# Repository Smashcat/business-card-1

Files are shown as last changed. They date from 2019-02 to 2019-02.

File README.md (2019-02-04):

# business-card-1
LED business card with a 15 x 5 LED matrix. Using ATMega168PB microcontroller, and real time clock chip. Powered by single CR2032 coin cell. All SMD parts, so if you're having PCBs made with this design I'd strongly suggest also buying a stencil to make it a LOT easier to solder! In my code I'm using deep sleep, with the button triggering a pin change interrupt to wake it. I use a 10khz timer interrupt to multiplexthe LEDs, which gives a good brightness, and allows for at least 16 greyscale levels.

Note that I'm using 100ohm resistors for the rows - this allows you to run the card at both 3v and 5v - however if you're only using 3v, I'd suggest lowering the resistor value to 50ohms, to increase brightness. 3D printing an acrylic cover to diffuse the LEDs would be a nice touch too! If I get a design done I'll add it here!

Image of card

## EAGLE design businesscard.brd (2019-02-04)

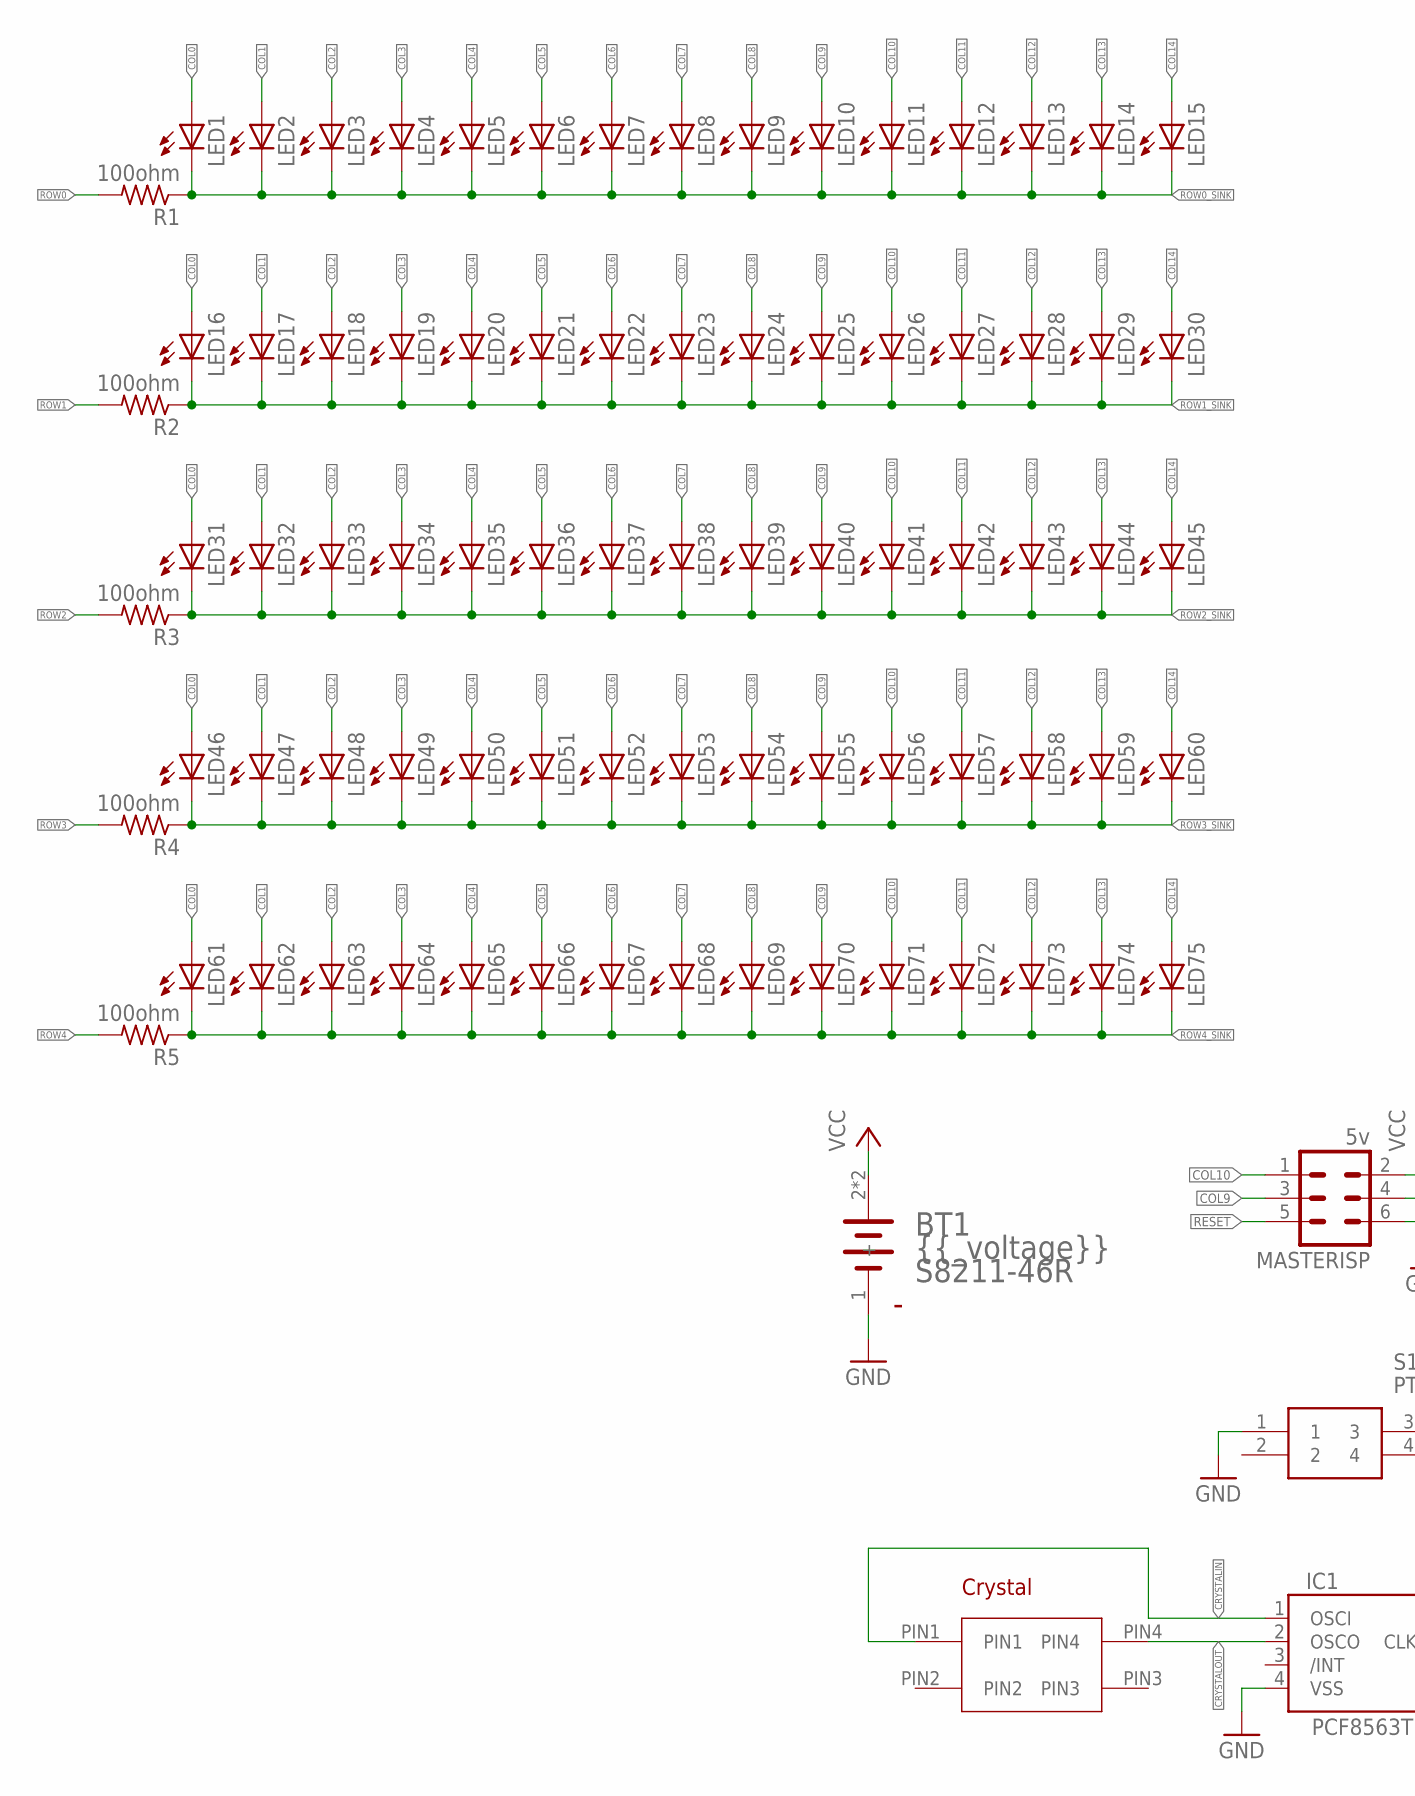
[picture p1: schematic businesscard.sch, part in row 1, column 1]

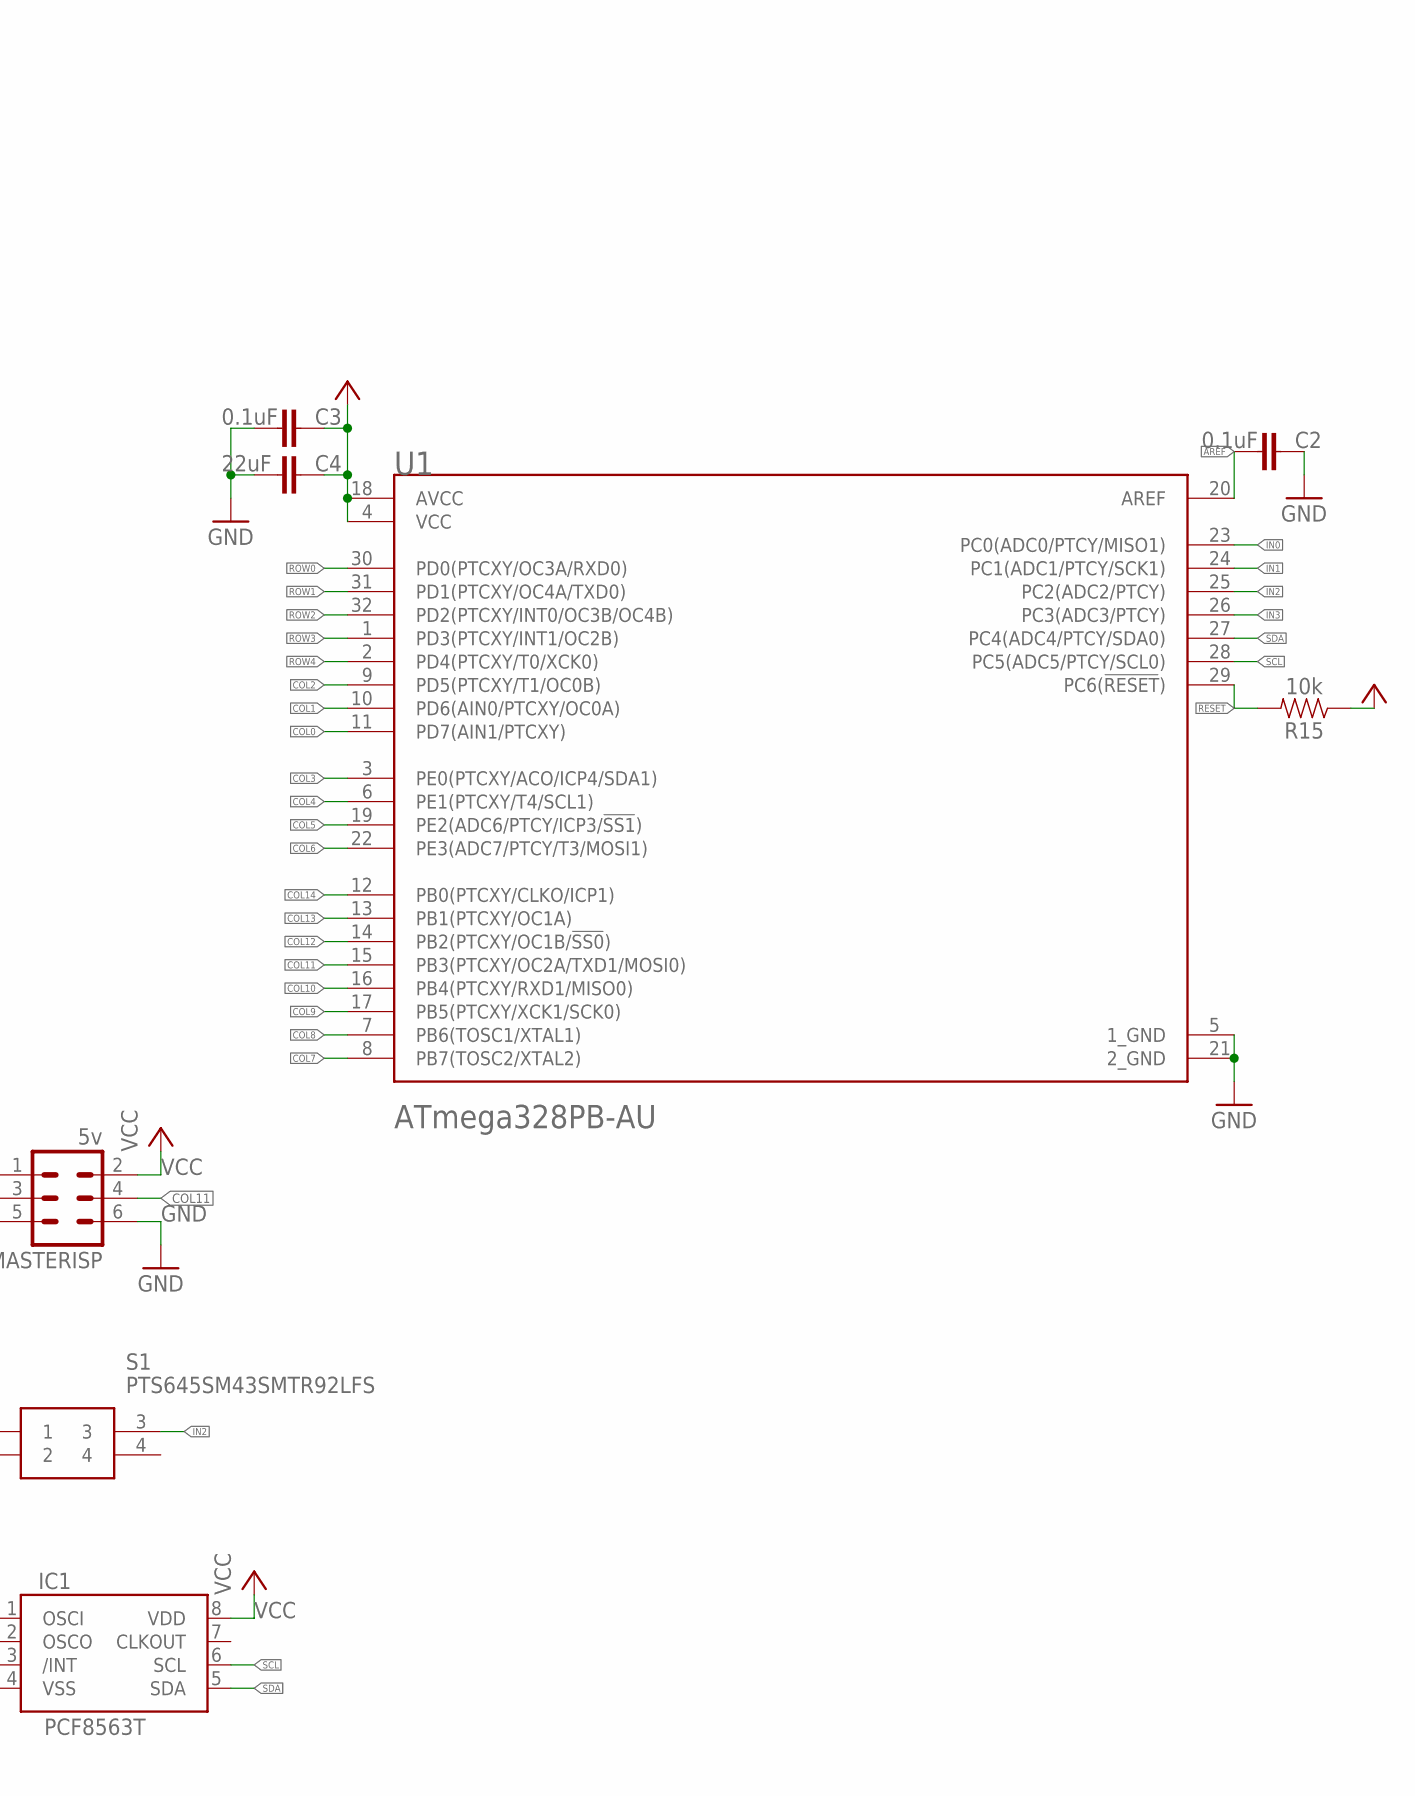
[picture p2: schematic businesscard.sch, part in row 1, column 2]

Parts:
BT1: 3v; HARWIN_S8211-46R_0
C2: 0.1uF; C0603
C3: 0.1uF; 0603
C4: 22uF; C0603
IC1: PCF8563T; SO8
LED1, LED2, LED3, LED4, LED5, LED6, LED7, LED8, LED9, LED10, LED11, LED12, LED13, LED14, LED15, LED16, LED17, LED18, LED19, LED20, LED21, LED22, LED23, LED24, LED25, LED26, LED27, LED28, LED29, LED30, LED31, LED32, LED33, LED34, LED35, LED36, LED37, LED38, LED39, LED40, LED41, LED42, LED43, LED44, LED45, LED46, LED47, LED48, LED49, LED50, LED51, LED52, LED53, LED54, LED55, LED56, LED57, LED58, LED59, LED60, LED61, LED62, LED63, LED64, LED65, LED66, LED67, LED68, LED69, LED70, LED71, LED72, LED73, LED74, LED75: LEDCHIPLED_0805; CHIPLED_0805
MASTERISP: 5v; MA03-2
R1, R2, R3, R4, R5: 100ohm; R0603
R15: 10k; 0603
S1: PTS645SM43SMTR92LFS; PTS645(SMT)
U1: MICROCHIP_ATMEGA328PB-AUMICROCHIP_ATMEGA328PB-AU_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; MICROCHIP_ATMEGA328PB-AU_0
U$1: 32.768_SMD_CRYSTAL

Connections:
AREF: C2.2, U1.20 (AREF)
COL0: LED1.A, LED16.A, LED31.A, LED46.A, LED61.A, U1.11 (PD7(AIN1/PTCXY))
COL1: LED2.A, LED17.A, LED32.A, LED47.A, LED62.A, U1.10 (PD6(AIN0/PTCXY/OC0A))
COL2: LED3.A, LED18.A, LED33.A, LED48.A, LED63.A, U1.9 (PD5(PTCXY/T1/OC0B))
COL3: LED4.A, LED19.A, LED34.A, LED49.A, LED64.A, U1.3 (PE0(PTCXY/ACO/ICP4/SDA1))
COL4: LED5.A, LED20.A, LED35.A, LED50.A, LED65.A, U1.6 (PE1(PTCXY/T4/SCL1))
COL5: LED6.A, LED21.A, LED36.A, LED51.A, LED66.A, U1.19 (PE2(ADC6/PTCY/ICP3/!SS1!))
COL6: LED7.A, LED22.A, LED37.A, LED52.A, LED67.A, U1.22 (PE3(ADC7/PTCY/T3/MOSI1))
COL7: LED8.A, LED23.A, LED38.A, LED53.A, LED68.A, U1.8 (PB7(TOSC2/XTAL2))
COL8: LED9.A, LED24.A, LED39.A, LED54.A, LED69.A, U1.7 (PB6(TOSC1/XTAL1))
COL9: LED10.A, LED25.A, LED40.A, LED55.A, LED70.A, MASTERISP.3, U1.17 (PB5(PTCXY/XCK1/SCK0))
COL10: LED11.A, LED26.A, LED41.A, LED56.A, LED71.A, MASTERISP.1, U1.16 (PB4(PTCXY/RXD1/MISO0))
COL11: LED12.A, LED27.A, LED42.A, LED57.A, LED72.A, MASTERISP.4, U1.15 (PB3(PTCXY/OC2A/TXD1/MOSI0))
COL12: LED13.A, LED28.A, LED43.A, LED58.A, LED73.A, U1.14 (PB2(PTCXY/OC1B/!SS0!))
COL13: LED14.A, LED29.A, LED44.A, LED59.A, LED74.A, U1.13 (PB1(PTCXY/OC1A))
COL14: LED15.A, LED30.A, LED45.A, LED60.A, LED75.A, U1.12 (PB0(PTCXY/CLKO/ICP1))
CRYSTALIN: IC1.1 (OSCI), U$1.PIN1
CRYSTALOUT: IC1.2 (OSCO), U$1.PIN4
GND: BT1.1 (-), C2.1, C3.2, C4.2, IC1.4 (VSS), MASTERISP.6, S1.1, U1.5 (1_GND), U1.21 (2_GND)
IN0: U1.23 (PC0(ADC0/PTCY/MISO1))
IN1: U1.24 (PC1(ADC1/PTCY/SCK1))
IN2: S1.3, U1.25 (PC2(ADC2/PTCY))
IN3: U1.26 (PC3(ADC3/PTCY))
RESET: MASTERISP.5, R15.2, U1.29 (PC6(!RESET!))
ROW0: R1.2, U1.30 (PD0(PTCXY/OC3A/RXD0))
ROW0_SINK: LED1.C, LED2.C, LED3.C, LED4.C, LED5.C, LED6.C, LED7.C, LED8.C, LED9.C, LED10.C, LED11.C, LED12.C, LED13.C, LED14.C, LED15.C, R1.1
ROW1: R2.2, U1.31 (PD1(PTCXY/OC4A/TXD0))
ROW1_SINK: LED16.C, LED17.C, LED18.C, LED19.C, LED20.C, LED21.C, LED22.C, LED23.C, LED24.C, LED25.C, LED26.C, LED27.C, LED28.C, LED29.C, LED30.C, R2.1
ROW2: R3.2, U1.32 (PD2(PTCXY/INT0/OC3B/OC4B))
ROW2_SINK: LED31.C, LED32.C, LED33.C, LED34.C, LED35.C, LED36.C, LED37.C, LED38.C, LED39.C, LED40.C, LED41.C, LED42.C, LED43.C, LED44.C, LED45.C, R3.1
ROW3: R4.2, U1.1 (PD3(PTCXY/INT1/OC2B))
ROW3_SINK: LED46.C, LED47.C, LED48.C, LED49.C, LED50.C, LED51.C, LED52.C, LED53.C, LED54.C, LED55.C, LED56.C, LED57.C, LED58.C, LED59.C, LED60.C, R4.1
ROW4: R5.2, U1.2 (PD4(PTCXY/T0/XCK0))
ROW4_SINK: LED61.C, LED62.C, LED63.C, LED64.C, LED65.C, LED66.C, LED67.C, LED68.C, LED69.C, LED70.C, LED71.C, LED72.C, LED73.C, LED74.C, LED75.C, R5.1
SCL: IC1.6 (SCL), U1.28 (PC5(ADC5/PTCY/SCL0))
SDA: IC1.5 (SDA), U1.27 (PC4(ADC4/PTCY/SDA0))
VCC: BT1.2 (+), BT1.2-2 (+), C3.1, C4.1, IC1.8 (VDD), MASTERISP.2, R15.1, U1.4 (VCC), U1.18 (AVCC)

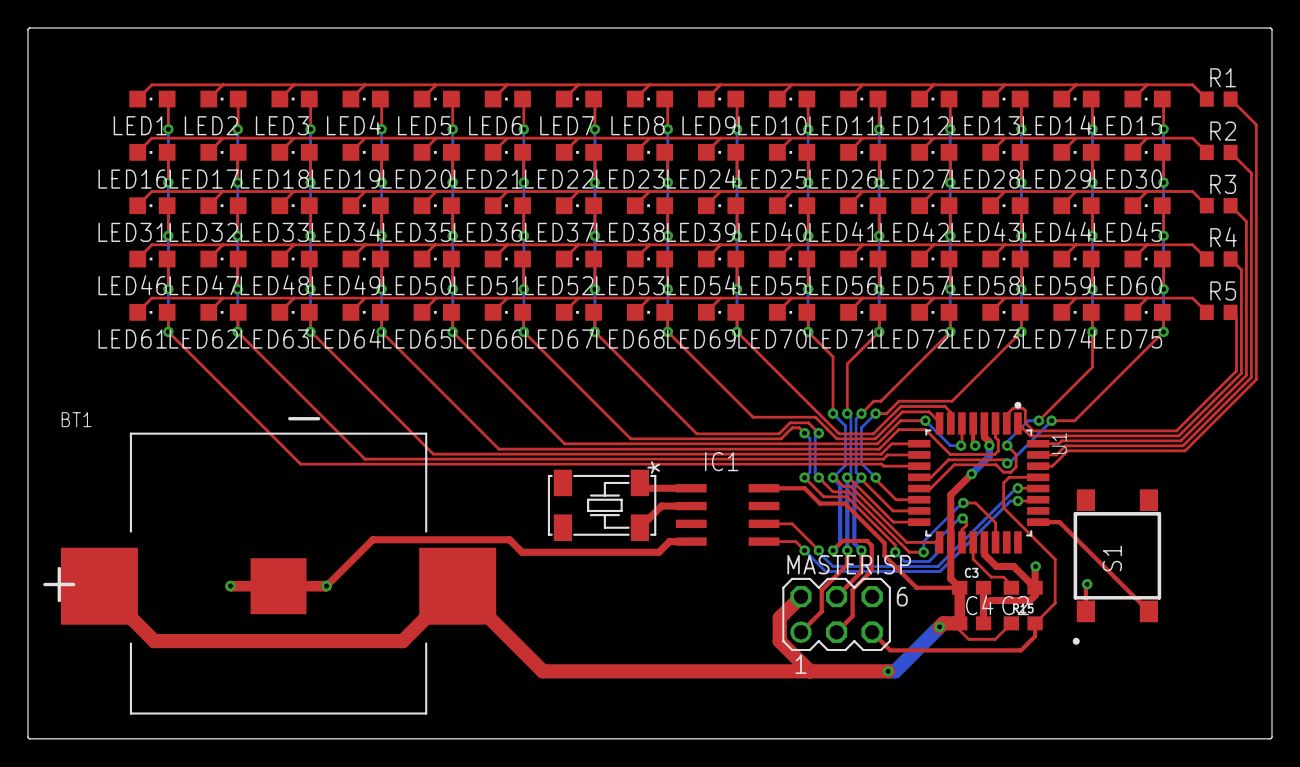
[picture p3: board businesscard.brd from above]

Board: 2 copper layers, 88.9 x 50.8 mm, 90 parts (0 on the bottom side), 34 nets.

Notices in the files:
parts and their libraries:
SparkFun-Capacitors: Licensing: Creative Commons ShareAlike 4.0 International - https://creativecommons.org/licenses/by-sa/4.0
